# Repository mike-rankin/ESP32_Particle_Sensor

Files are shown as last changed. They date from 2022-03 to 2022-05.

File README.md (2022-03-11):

# ESP32_Particle_Sensor
ESP32_Particle_Sensor



This project is an ESP32 internet of things desktop particle sensor. It was created as an excuse to try out a new air particle sensor that I came across. This project shows the level of particles in the air, date, time, wifi strength, temperature, humidity, atmospheric pressure and gas value. Time is updated every minute minutes over wifi from an NTP server. 

Hardware on this board:<br/>
-ESP32 Wroom processor<br/>
-air sensor (Bosch BME680)<br/>
-particle sensor(PMSA003-A)<br/>
-240x240 TFT LCD (ER-TFT1.54-1)<br/>
-3.3V LDO (NCP1117LPST33T3G)<br/>
-USB interface (CP2104N)<br/>
-USB-C Connector<br/>
-QwiiC i2c Connector<br/>

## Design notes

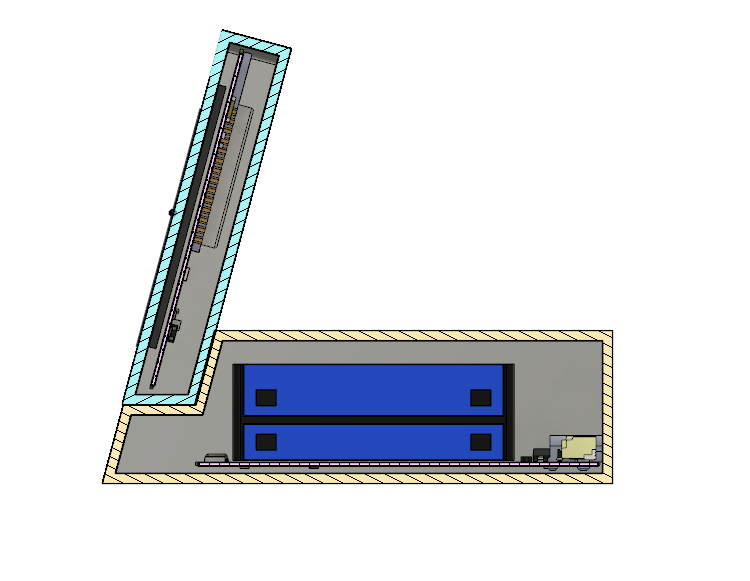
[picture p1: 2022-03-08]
Images/internals.png

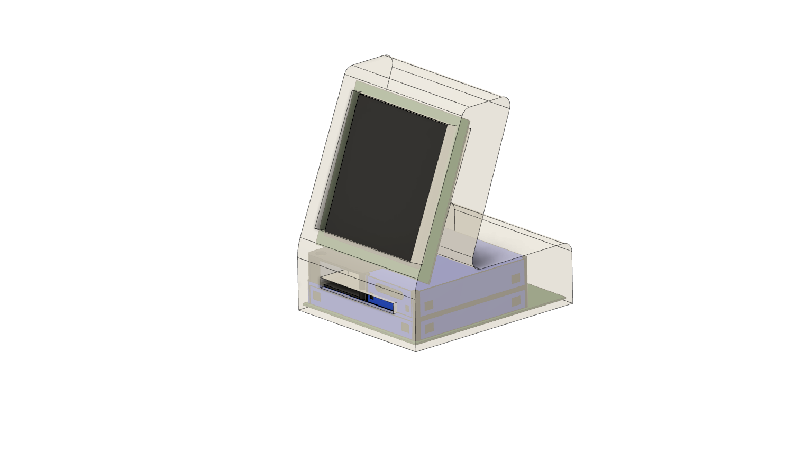
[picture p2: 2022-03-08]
Images/Angle.png

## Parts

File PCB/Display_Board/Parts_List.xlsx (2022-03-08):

Designator | Quantity | Vendor | Part_Number | Description | Manufacturer | Value
C1 | 1 | LCSC | C307520 | CAP 10uF 0805 | Samsung | 10uF
C2, C3, C5 | 3 | LCSC | C60474 | CAP 0.1uF 0402 | Yageo | 0.1uF
C4, C6 | 2 | LCSC | C77101 | CAP 47uF 1210 | Murata | 47uF
C7 | 1 | LCSC | C83063 | CAP 1uF 16V 0402 | Walsin | 1uF
Q2 | 1 | LCSC | C148112 | TRANS 2NPN 44V 0.1A SC-70-6 | Changjiang | BC847S
R1 | 1 | LCSC | C25092 | RES 22R 0402 | Uniroyal | 22R
R3, R5, R6, R7 | 4 | LCSC | C258091 | RES 10K 0402 | Guangdong | 10K
U1 | 1 | Digi-Key | ESP32-WROOM-32D-N4 | WIFI/Bluetooth, SMD Module | Espressif | ESP32-WROOM
U2 | 1 | LCSC | C47742 | IC BRIDGE USB TO UART 24QFN | Silicon Labs | CP2104N
X1 | 1 | BuyDisplay | ER-TFT1.54-1 | 1.54 INCH TFT GLASS COLOR | BuyDisplay | TFT_1.54"

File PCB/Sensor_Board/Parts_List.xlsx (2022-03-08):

Designator | Quantity | Comment | Vendor | Description | Part_Number | Manufacturer | Value
C1 | 1 | 0.1uF | LCSC | CAP 0.1uF 0402 | C60474 | Yageo | 0.1uF
C2, C3 | 2 | 10uF | LCSC | CAP 10uF 0805 | C307520 | Samsung | 10uF
C4 | 1 | 47uF | LCSC | CAP 47uF 1210 | C77101 | Murata | 47uF
D1 | 1 | Green Led | LCSC | LED Green 0402 | C74338 | Everlight | Green Led
F1 | 1 | TLC-PSMD050 | LCSC | PTC FUSE 500mA hold, 1A | C261942 | TLC | TLC-PSMD050
H1 | 1 | PMSA003-A | LCSC | Dust Particle Sensor I2C | C132744 | Plantower | PMSA003-A
H3 | 1 | QWiiC | LCSC | CONN HEADER 4POS .100 R/A QWIIC | C160404 | JST | QWiiC
J1 | 1 | USB-C | LCSC | CONN RECPT USB-C | C165948 | KHE | USB-C
R1, R3 | 2 | 5.1K | LCSC | RES 5.1K 0402 | C25905 | Uniroyal | 5.1K
R2 | 1 | 22K | LCSC | RES 22K 0402 | C100310 | LIZ Elec | 22K
R6, R7, R8, R9 | 4 | 10K | LCSC | RES 10K 0402 | C258091 | Guangdong | 10K
U1 | 1 | NCP1117LPST33T3G | LCSC | IC REG LDO 3.3V 1A SOT223-3 | C146799 | ON Semi | 3.3V 1A LDO
U2 | 1 | BME680 | Digi-Key | Sensor I2C, | BME680 | Bosch | BME680

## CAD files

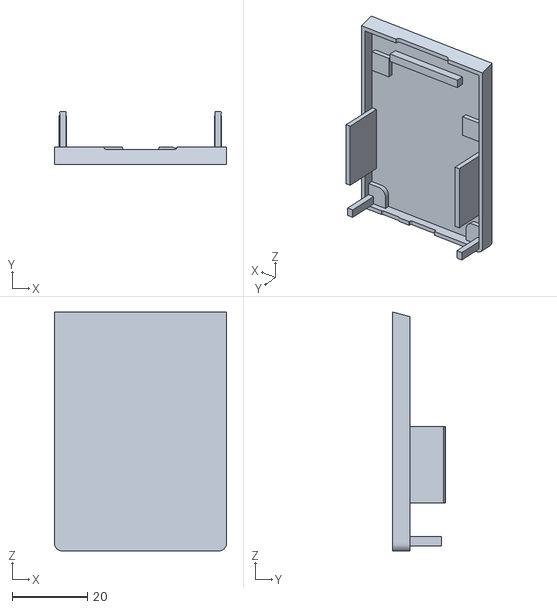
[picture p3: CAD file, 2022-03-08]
Enclosure/Bottom_Lower.stl
45.7 x 14.0 x 63.5

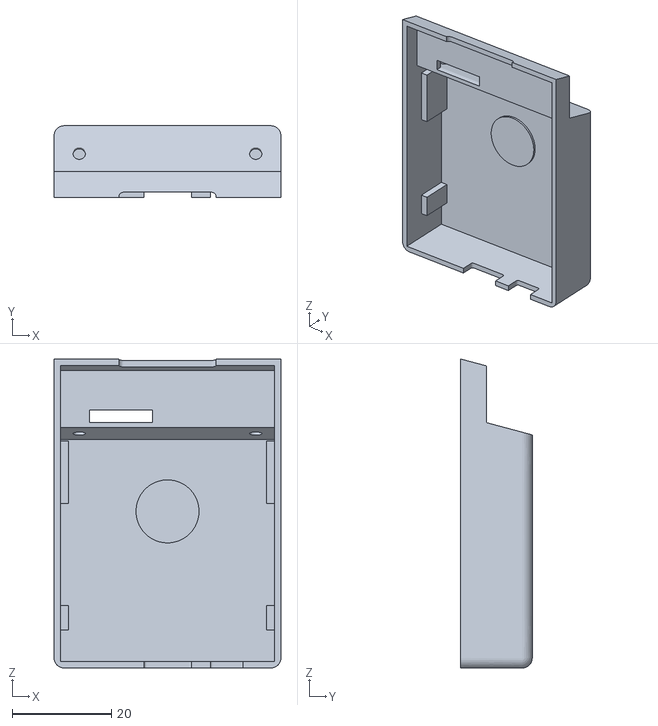
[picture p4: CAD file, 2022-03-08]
Enclosure/Bottom_Upper.stl
45.7 x 14.4 x 62.3

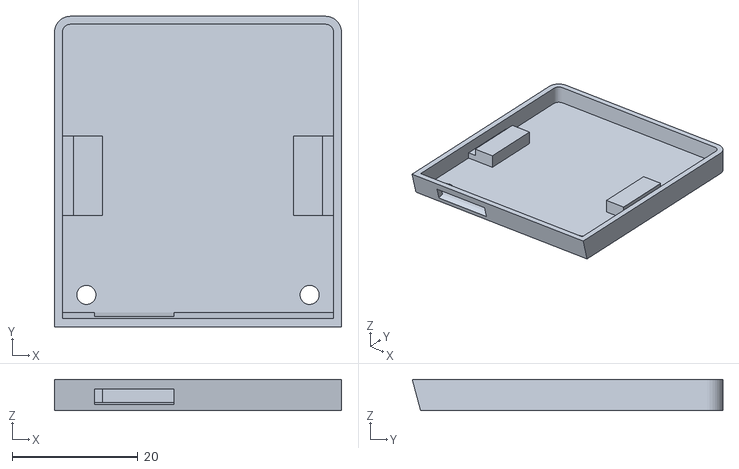
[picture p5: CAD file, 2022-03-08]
Enclosure/Top_Lower.stl
45.7 x 49.5 x 4.95

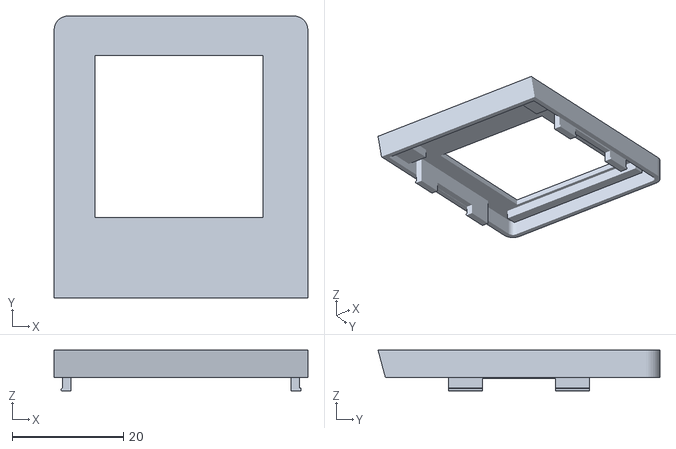
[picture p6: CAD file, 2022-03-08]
Enclosure/Top_Front.stl
45.7 x 50.8 x 7.37

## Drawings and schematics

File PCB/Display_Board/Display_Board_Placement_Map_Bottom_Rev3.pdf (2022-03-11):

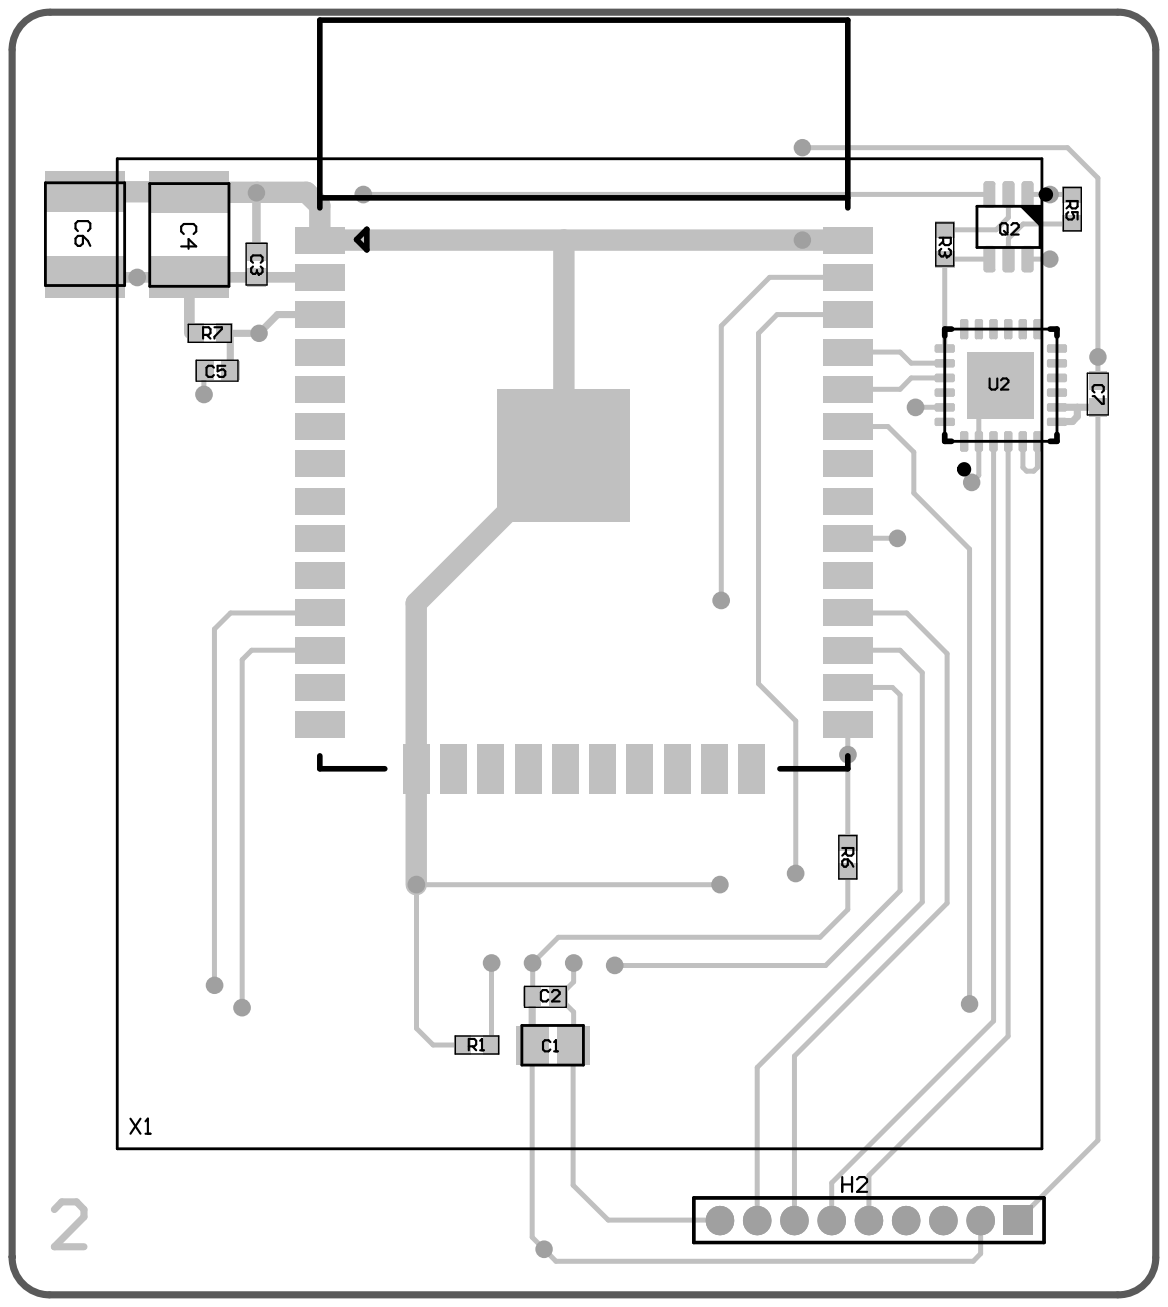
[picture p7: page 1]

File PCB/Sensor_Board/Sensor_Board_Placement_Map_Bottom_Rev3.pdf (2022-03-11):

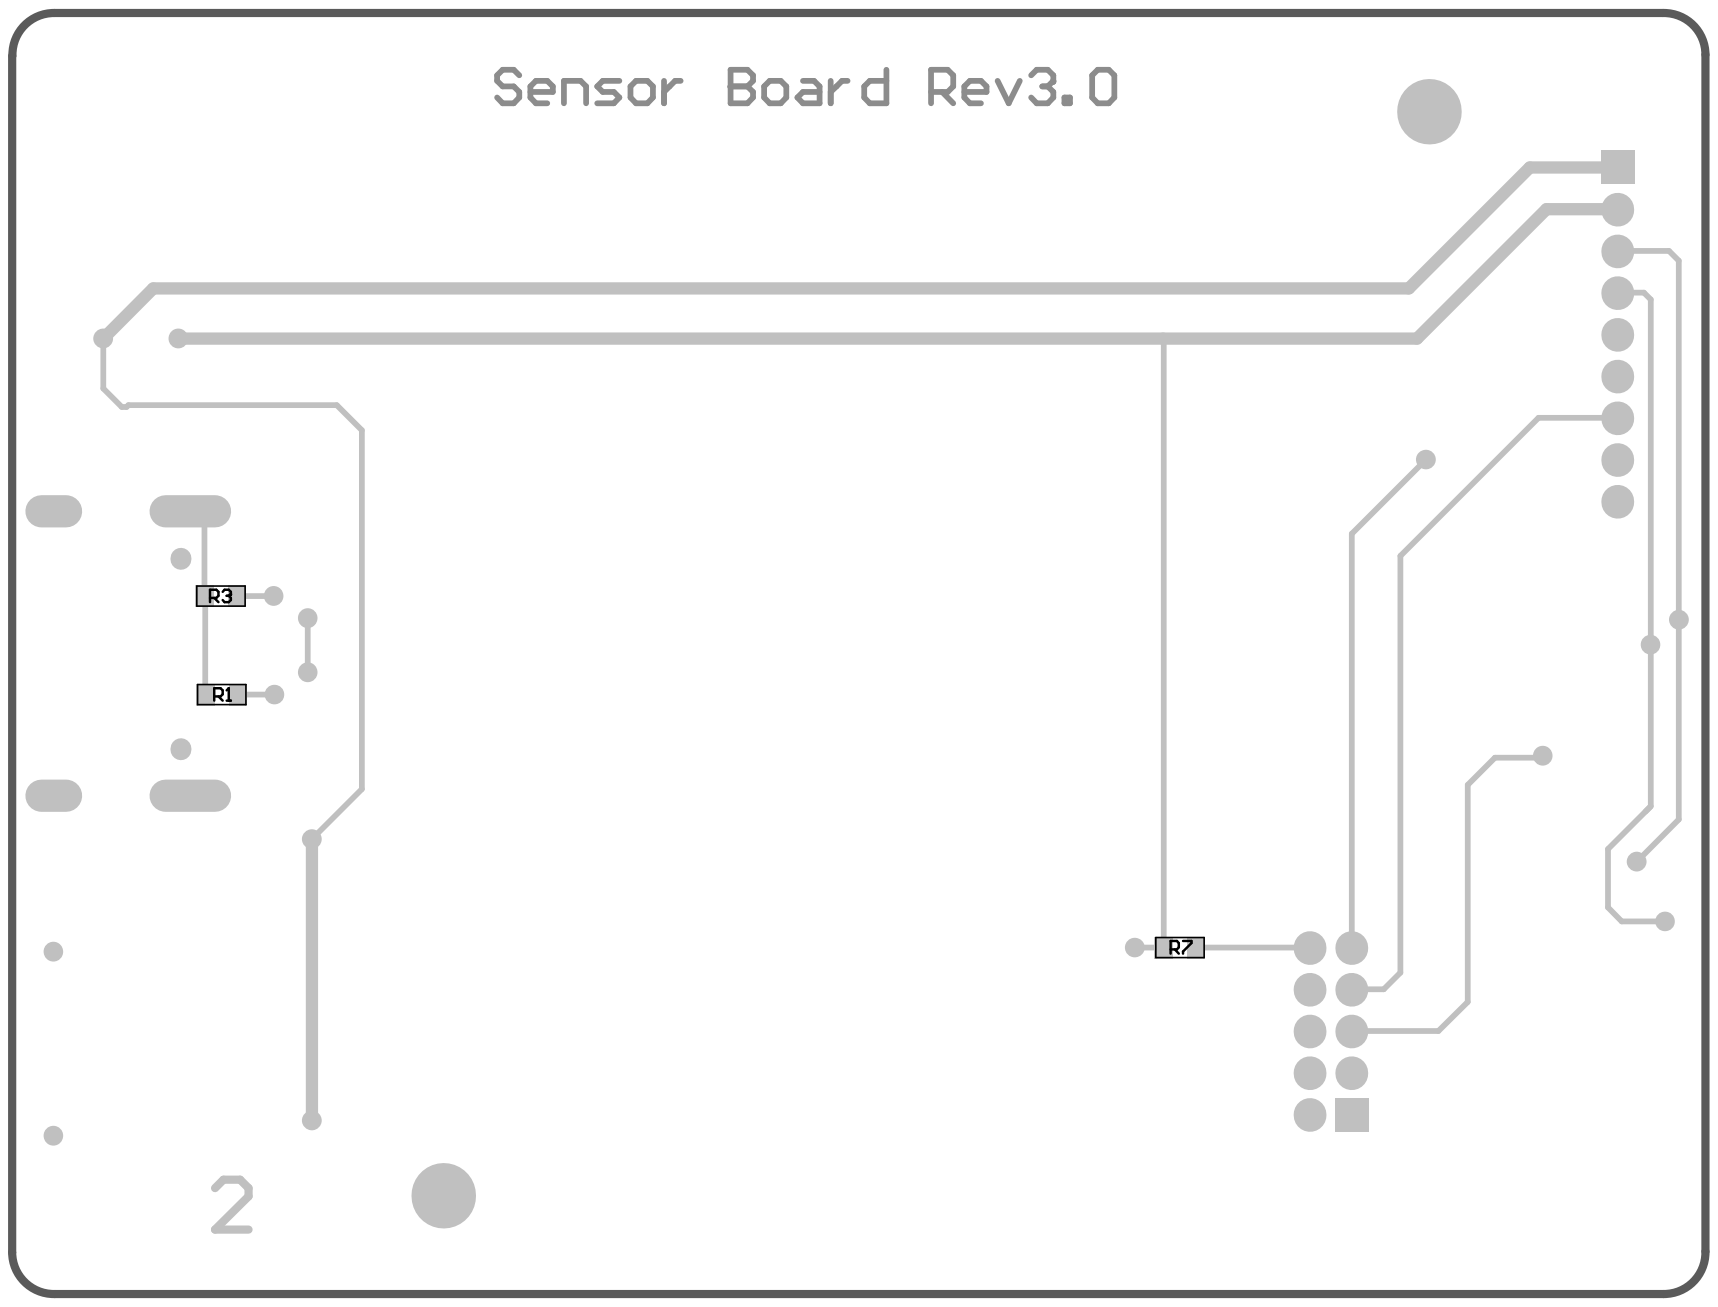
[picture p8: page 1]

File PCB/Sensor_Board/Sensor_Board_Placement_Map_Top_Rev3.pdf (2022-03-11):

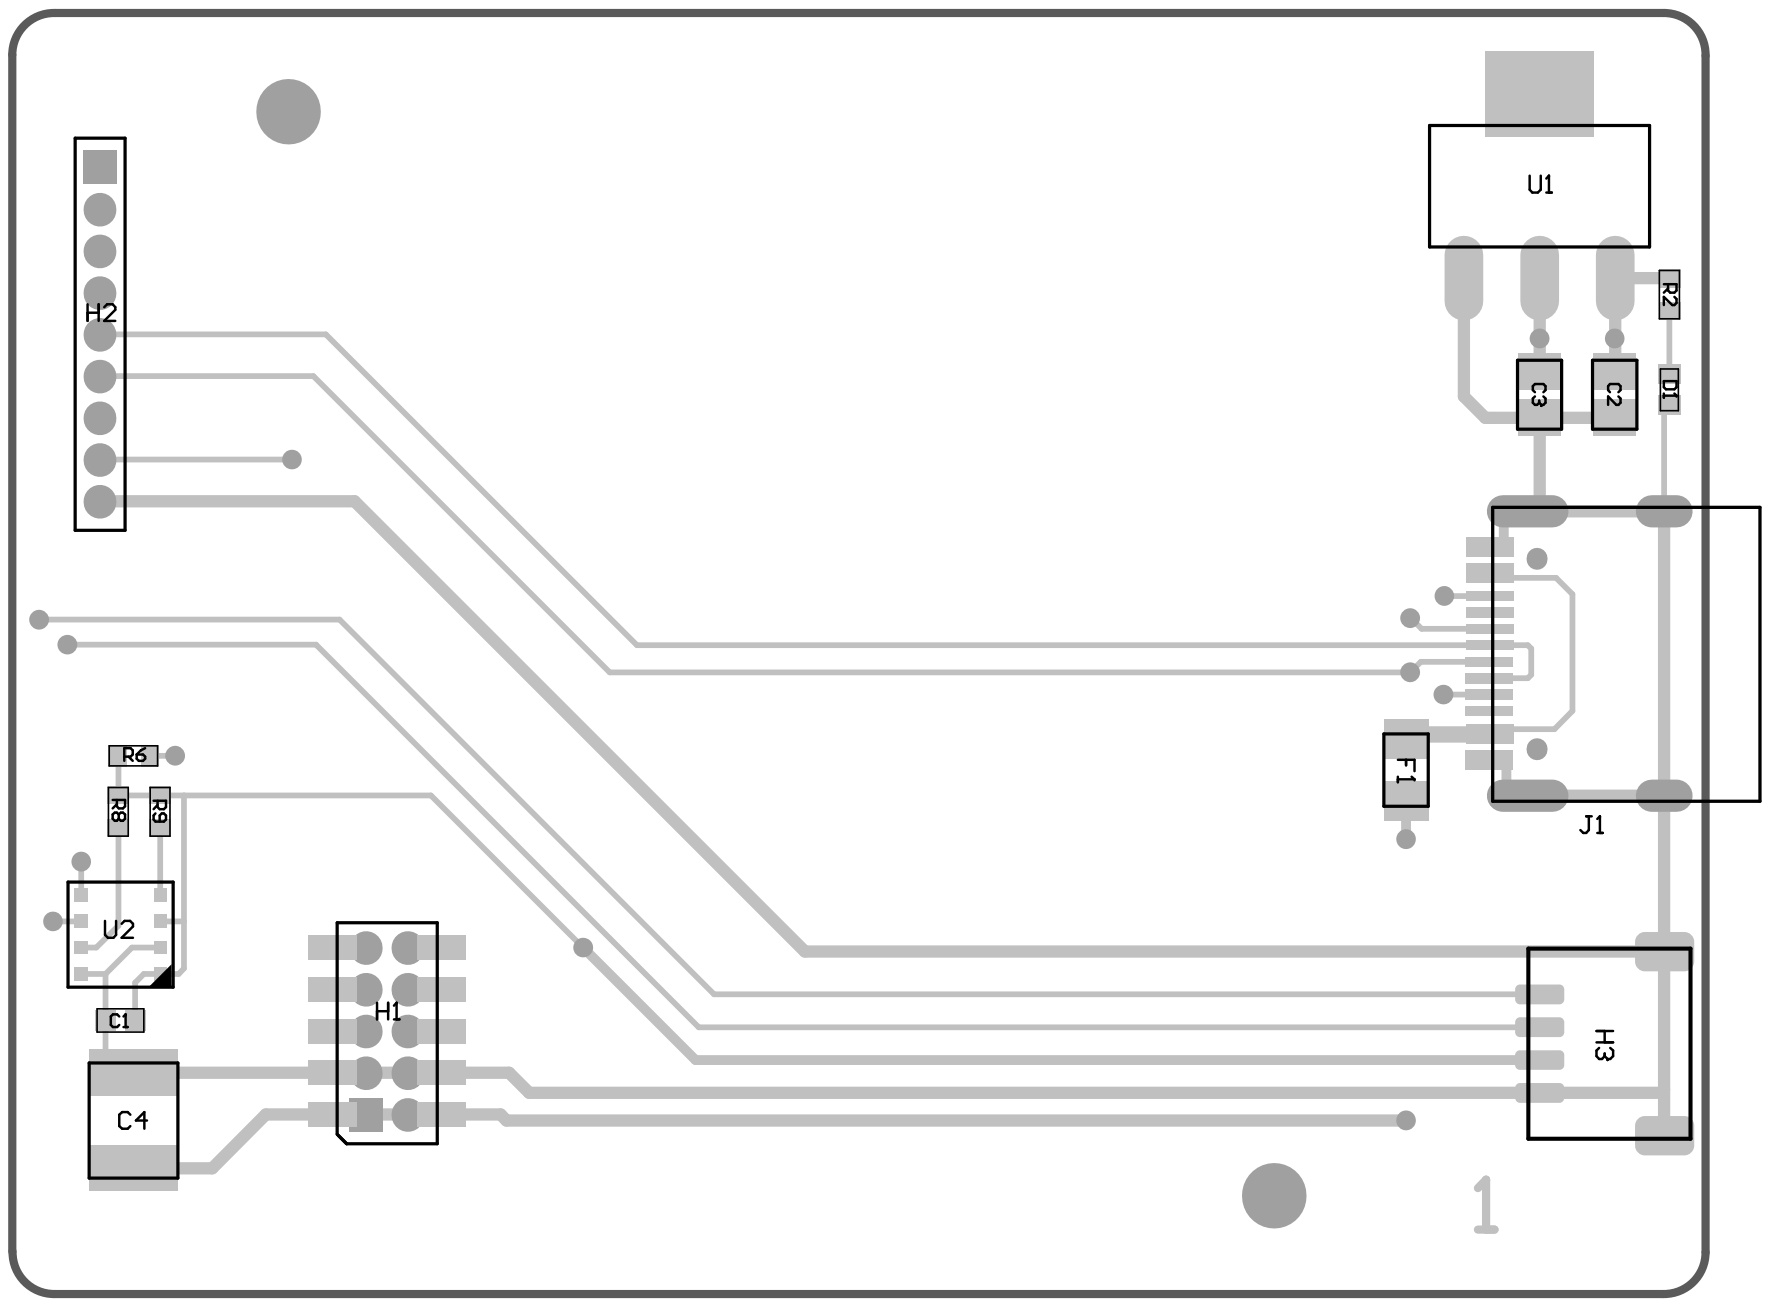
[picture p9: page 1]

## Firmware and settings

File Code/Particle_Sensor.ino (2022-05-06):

/* Sensor Test sketch */
//Image Converter Used: http://www.rinkydinkelectronics.com/_t_doimageconverter565.php

#include "Adafruit_PM25AQI.h"
#include <Adafruit_Sensor.h>
#include "Adafruit_BME680.h"
#include <TFT_eSPI.h> 
#include <Wire.h>
#include <SPI.h>
#include <NTPClient.h>           //https://github.com/taranais/NTPClient
#include <WiFi.h>
//#include "WiFi.h"
#include <WiFiUdp.h>
#include <HTTPClient.h>          //Needed for the date
#include "font.h"
#include "overlay.h"
#include "Wifi_Icons.h"

#define RXD2 16
#define TXD2 17
#define SEALEVELPRESSURE_HPA (1013.25)
#define temperaure_offset (6.7)  

Adafruit_BME680 bme;
Adafruit_PM25AQI aqi = Adafruit_PM25AQI();

TFT_eSPI tft = TFT_eSPI(); 
WiFiUDP ntpUDP;
NTPClient timeClient(ntpUDP, "pool.ntp.org");
String formattedDate;
String dayStamp;
uint32_t targetTime = 0;      
const long interval = 60000;  //Update every minute
unsigned long previousMillis = 0;   

const char *ssid     = "SSID";        
const char *password = "PASSWORD";      


void setup() 
{
  tft.init();
  tft.setSwapBytes(true);
  tft.setRotation(0);
  tft.fillScreen(TFT_BLACK);
  Serial.begin(115200);
  while (!Serial) delay(10);
  tft.setTextColor(TFT_GREEN,TFT_BLACK);
  tft.setTextSize(2);
  Serial.println("Wii Test");
  Serial.print("Connecting to ");
  tft.println("Connecting to Wifi");
  Serial.println(ssid);
  WiFi.begin(ssid, password);
  
  while (WiFi.status() != WL_CONNECTED) 
  {
   delay(500);
   Serial.print(".");
   tft.print(".");
  }
 
  tft.println(" ");
  tft.println(" ");
  tft.println("WiFi connected.");
  tft.println("IP address: ");
  tft.println(WiFi.localIP());
  Serial.println(WiFi.localIP());
  delay(3000);

  if (!bme.begin()) 
  {
   Serial.println("Could not find a valid BME680 sensor, check wiring!");
   while (1);
  }

  //Set up oversampling and filter initialization
  bme.setTemperatureOversampling(BME680_OS_8X);
  bme.setHumidityOversampling(BME680_OS_2X);
  bme.setPressureOversampling(BME680_OS_4X);
  bme.setIIRFilterSize(BME680_FILTER_SIZE_3);
  bme.setGasHeater(320, 150); 

  Serial2.begin(9600, SERIAL_8N1, RXD2, TXD2);
  
  if (! aqi.begin_UART(&Serial2)) 
  { 
   Serial.println("Could not find PM 2.5 sensor!");
   while (1) delay(10);
  }

  Serial.println("PM25 found!");
 
  tft.fillScreen(TFT_BLACK);
 
  tft.pushImage(0,0,240,240,overlay);
  
  timeClient.begin();
  timeClient.setTimeOffset(-10800);  //-14400 or -10800
  delay(500);
  timeClient.update();
}



void loop() 
{
 unsigned long currentMillis = millis(); 
 int currentHour;
 int currentMinute;
 int currentDay;
  
 tft.setTextColor(TFT_GREEN,TFT_BLACK);
 tft.setTextSize(2); 
 
 if (currentMillis - previousMillis >= interval) 
 {
  previousMillis = currentMillis; 
  timeClient.update();
  Serial.println("Time Updated");
 }

  tft.setTextSize(1);
  tft.setCursor (0, 7); 
  tft.print(__DATE__);
  tft.setCursor (100, 7); 
  tft.print(__TIME__);
  
  tft.setTextSize(2);  //fixes font for PM2.5
  WifiIcon(); 


 PM25_AQI_Data data;
 if (! aqi.read(&data)) 
 {
  Serial.println("Could not read from AQI");
  delay(500);  
  return;
 }
  Serial.println("AQI reading success");

  Serial.print(F("\t\tPM 2.5: ")); Serial.print(data.pm25_standard);
  
 
  
  tft.setTextColor(TFT_ORANGE,TFT_BLACK);                                             
  uint16_t x = tft.width()/2;   // Find centre of screen
  tft.setTextDatum(MC_DATUM);   // Set datum to Middle Center
  int padding = tft.textWidth("8888", 4);
  tft.setTextPadding(padding);
  tft.drawNumber(data.pm25_standard, x, 60, 4);
 

  
  tft.setCursor(180, 65);
  tft.setTextSize(2); 
  tft.print("PM2.5");

  tft.setTextColor(TFT_SKYBLUE,TFT_BLACK);
  tft.setTextSize(2);

  tft.setCursor(50, 118);
  tft.print((bme.temperature-temperaure_offset),1);  

  tft.setCursor(55, 138);
  tft.println("÷C");

  tft.setCursor(165, 118);
  tft.print(bme.pressure / 100.0,1);

  tft.setCursor(168, 138);
  tft.println("hPa");

  tft.setTextColor(TFT_SKYBLUE,TFT_BLACK); 

  tft.setTextSize(2);
  tft.setCursor(50, 190); 
 
  tft.print(bme.humidity,1);
  bme.humidity;

  tft.setCursor(60, 210);
  tft.println("%");

  tft.setCursor(165, 190); 

  tft.print(bme.gas_resistance / 1000.0,1);

  tft.setCursor(168, 210);
  tft.println("KOhms");

  bme.readAltitude(SEALEVELPRESSURE_HPA);
  delay(50);  
}

 void WifiIcon() 
 {
  int32_t dbmicon = WiFi.RSSI();
   
  if (dbmicon <= -80 )  
  {
   tft.pushImage(225,0,16,16,wifi_1);
  } 

  else if (dbmicon <= -50 && dbmicon >= -79)
  {
   tft.pushImage(225,0,16,16,wifi_2);
  }

 else if (dbmicon >= -49)  
  {
   tft.pushImage(225,0,16,16,wifi_3);
  }
}

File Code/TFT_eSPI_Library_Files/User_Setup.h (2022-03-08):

//                            USER DEFINED SETTINGS
//   Set driver type, fonts to be loaded, pins used and SPI control method etc
//
//   See the User_Setup_Select.h file if you wish to be able to define multiple
//   setups and then easily select which setup file is used by the compiler.
//
//   If this file is edited correctly then all the library example sketches should
//   run without the need to make any more changes for a particular hardware setup!
//   Note that some sketches are designed for a particular TFT pixel width/height


// ##################################################################################
//
// Section 1. Call up the right driver file and any options for it
//
// ##################################################################################

// Define STM32 to invoke optimised processor support (only for STM32)
//#define STM32

// Defining the STM32 board allows the library to optimise the performance
// for UNO compatible "MCUfriend" style shields
//#define NUCLEO_64_TFT
//#define NUCLEO_144_TFT

// STM32 8 bit parallel only:
// If STN32 Port A or B pins 0-7 are used for 8 bit parallel data bus bits 0-7
// then this will improve rendering performance by a factor of ~8x
//#define STM_PORTA_DATA_BUS
//#define STM_PORTB_DATA_BUS

// Tell the library to use 8 bit parallel mode (otherwise SPI is assumed)
//#define TFT_PARALLEL_8_BIT

// Display type -  only define if RPi display
//#define RPI_DISPLAY_TYPE // 20MHz maximum SPI

// Only define one driver, the other ones must be commented out
//#define ILI9341_DRIVER       // Generic driver for common displays
//#define ILI9341_2_DRIVER     // Alternative ILI9341 driver, see https://github.com/Bodmer/TFT_eSPI/issues/1172
//#define ST7735_DRIVER      // Define additional parameters below for this display
//#define ILI9163_DRIVER     // Define additional parameters below for this display
//#define S6D02A1_DRIVER
//#define RPI_ILI9486_DRIVER // 20MHz maximum SPI
//#define HX8357D_DRIVER
//#define ILI9481_DRIVER
//#define ILI9486_DRIVER
//#define ILI9488_DRIVER     // WARNING: Do not connect ILI9488 display SDO to MISO if other devices share the SPI bus (TFT SDO does NOT tristate when CS is high)
#define ST7789_DRIVER      // Full configuration option, define additional parameters below for this display
//#define ST7789_2_DRIVER    // Minimal configuration option, define additional parameters below for this display
//#define R61581_DRIVER
//#define RM68140_DRIVER
//#define ST7796_DRIVER
//#define SSD1351_DRIVER
//#define SSD1963_480_DRIVER
//#define SSD1963_800_DRIVER
//#define SSD1963_800ALT_DRIVER
//#define ILI9225_DRIVER
//#define GC9A01_DRIVER

// Some displays support SPI reads via the MISO pin, other displays have a single
// bi-directional SDA pin and the library will try to read this via the MOSI line.
// To use the SDA line for reading data from the TFT uncomment the following line:

// #define TFT_SDA_READ      // This option is for ESP32 ONLY, tested with ST7789 and GC9A01 display only

// For ST7735, ST7789 and ILI9341 ONLY, define the colour order IF the blue and red are swapped on your display
// Try ONE option at a time to find the correct colour order for your display

//  #define TFT_RGB_ORDER TFT_RGB  // Colour order Red-Green-Blue
//  #define TFT_RGB_ORDER TFT_BGR  // Colour order Blue-Green-Red

// For M5Stack ESP32 module with integrated ILI9341 display ONLY, remove // in line below

// #define M5STACK

// For ST7789, ST7735, ILI9163 and GC9A01 ONLY, define the pixel width and height in portrait orientation
// #define TFT_WIDTH  80
// #define TFT_WIDTH  128
 #define TFT_WIDTH  240 // ST7789 240 x 240 and 240 x 320
// #define TFT_HEIGHT 160
// #define TFT_HEIGHT 128
// #define TFT_HEIGHT 240 // ST7789 240 x 240
// #define TFT_HEIGHT 320 // ST7789 240 x 320
// #define TFT_HEIGHT 240 // GC9A01 240 x 240

// For ST7735 ONLY, define the type of display, originally this was based on the
// colour of the tab on the screen protector film but this is not always true, so try
// out the different options below if the screen does not display graphics correctly,
// e.g. colours wrong, mirror images, or stray pixels at the edges.
// Comment out ALL BUT ONE of these options for a ST7735 display driver, save this
// this User_Setup file, then rebuild and upload the sketch to the board again:

// #define ST7735_INITB
// #define ST7735_GREENTAB
// #define ST7735_GREENTAB2
// #define ST7735_GREENTAB3
// #define ST7735_GREENTAB128    // For 128 x 128 display
// #define ST7735_GREENTAB160x80 // For 160 x 80 display (BGR, inverted, 26 offset)
// #define ST7735_REDTAB
// #define ST7735_BLACKTAB
// #define ST7735_REDTAB160x80   // For 160 x 80 display with 24 pixel offset

// If colours are inverted (white shows as black) then uncomment one of the next
// 2 lines try both options, one of the options should correct the inversion.

// #define TFT_INVERSION_ON
// #define TFT_INVERSION_OFF


// ##################################################################################
//
// Section 2. Define the pins that are used to interface with the display here
//
// ##################################################################################

// If a backlight control signal is available then define the TFT_BL pin in Section 2
// below. The backlight will be turned ON when tft.begin() is called, but the library
// needs to know if the LEDs are ON with the pin HIGH or LOW. If the LEDs are to be
// driven with a PWM signal or turned OFF/ON then this must be handled by the user
// sketch. e.g. with digitalWrite(TFT_BL, LOW);

// #define TFT_BL   32            // LED back-light control pin
// #define TFT_BACKLIGHT_ON HIGH  // Level to turn ON back-light (HIGH or LOW)
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
